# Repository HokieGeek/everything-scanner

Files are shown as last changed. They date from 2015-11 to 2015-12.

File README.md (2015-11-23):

# Olive's Scanner 

Toy I am making my toddler so that when she touches an object the "scanner" vibrates and lights up. Should second as a flashlight, of sorts.

### Prototype

Current
[Album](http://imgur.com/a/BFDh3)

## Design

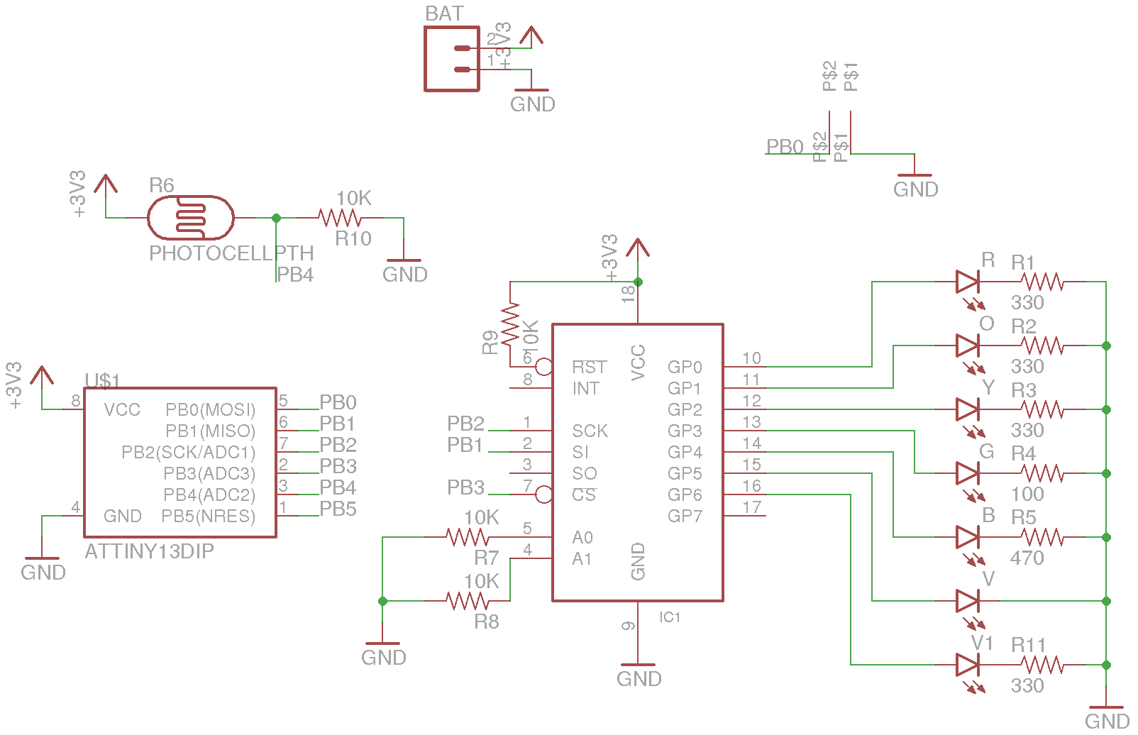
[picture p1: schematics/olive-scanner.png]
Schematics

Board

## Parts list

* [ATtiny13A](http://www.atmel.com/images/doc8126.pdf) - The driver of the whole thing
* [MCP23S08](http://www.mouser.com/ds/2/268/21919b-65915.pdf) - SPI 8-bit I/O expander used to drive just the LEDs
* [SparkFun's LED Rainbow Pack](https://www.sparkfun.com/products/13767) - Got it in a recent order for free as a christmas giveaway
* [Vibrator motor from an old phone]() - Took it out of my waterlogged MotoX :-D
* [CdS Photocell](http://cdn.sparkfun.com/datasheets/Sensors/LightImaging/SEN-09088.pdf) - When she touches this sensor to an object, the LEDs and motor activate

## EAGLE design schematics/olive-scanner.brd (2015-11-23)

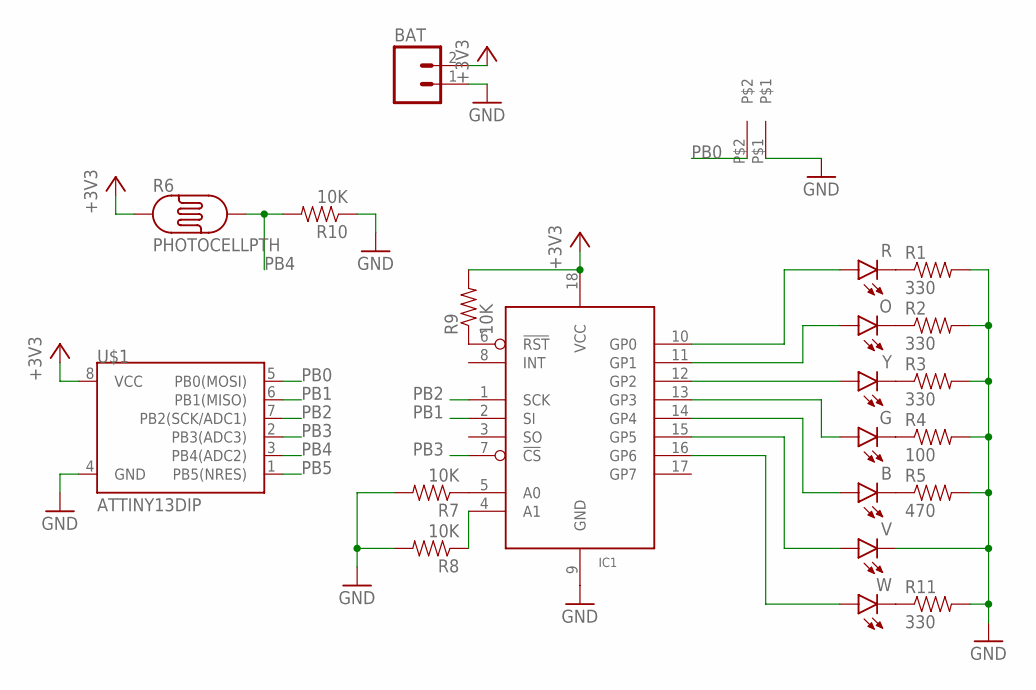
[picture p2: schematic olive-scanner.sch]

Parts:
B: LED5MM
BAT: M02LOCK; 1X02_LOCK
G: LED5MM
IC1: MCP23S08/P; DIL18
O: LED5MM
R: LED5MM
R1, R2, R3, R11: 330; AXIAL-0.3
R4: 100; AXIAL-0.3
R5: 470; AXIAL-0.3
R6: PHOTOCELLPTH; PHOTOCELL
R7, R8, R9, R10: 10K; AXIAL-0.3
U$1: ATTINY13DIP; DIP08
U$2: PHONE_VIBRATOR
V: LED5MM
W: LED5MM
Y: LED5MM

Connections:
+3V3: BAT.2, IC1.18 (VCC), R6.1, R9.P$2 (2), U$1.8 (VCC)
GND: BAT.1, IC1.9 (GND), R1.P$2 (2), R2.P$2 (2), R3.P$2 (2), R4.P$2 (2), R5.P$2 (2), R7.P$2 (2), R8.P$2 (2), R10.P$1 (1), R11.P$2 (2), U$1.4 (GND), U$2.P$1, V.K (C)
unnamed: IC1.4 (A1), R8.P$1 (1)
unnamed: IC1.6 (!RST), R9.P$1 (1)
unnamed: IC1.5 (A0), R7.P$1 (1)
unnamed: R.K (C), R1.P$1 (1)
unnamed: O.K (C), R2.P$1 (1)
unnamed: R3.P$1 (1), Y.K (C)
unnamed: G.K (C), R4.P$1 (1)
unnamed: B.K (C), R5.P$1 (1)
unnamed: R11.P$1 (1), W.K (C)
unnamed: IC1.16 (GP6), W.A
unnamed: IC1.10 (GP0), R.A
unnamed: IC1.11 (GP1), O.A
unnamed: IC1.12 (GP2), Y.A
unnamed: G.A, IC1.13 (GP3)
unnamed: B.A, IC1.14 (GP4)
unnamed: IC1.15 (GP5), V.A
PB0: U$1.5 (PB0(MOSI)), U$2.P$2
PB1: IC1.2 (SI), U$1.6 (PB1(MISO))
PB2: IC1.1 (SCK), U$1.7 (PB2(SCK/ADC1))
PB3: IC1.7 (!CS), U$1.2 (PB3(ADC3))
PB4: R6.2, R10.P$2 (2), U$1.3 (PB4(ADC2))
PB5: U$1.1 (PB5(NRES))

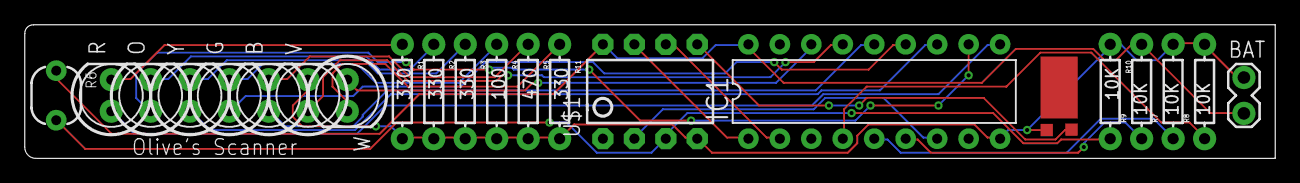
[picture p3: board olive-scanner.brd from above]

Board: 2 copper layers, 101.0 x 10.8 mm, 22 parts (0 on the bottom side), 23 nets.

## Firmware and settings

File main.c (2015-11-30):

// #define F_CPU 9600000UL

#include <avr/interrupt.h>
#include <avr/sleep.h>
#include <util/delay.h>

#include "mcp23x08.h"

#define FALSE 0
#define TRUE !(FALSE)

#define VIBRATOR_PIN PB0
#define VIBRATE_PULSE 255

#define LEDS_PIN_DATA PB1
#define LEDS_PIN_SERIALCLOCK PB2
#define LEDS_PIN_CHIPSELECT PB3
#define MCP23X08_SLAVE_ADDRESS_A0 0
#define MCP23X08_SLAVE_ADDRESS_A1 0
#define NUM_LEDS 6
#define NUM_LED_PATTERNS 4
#define ANIMATION_REPETITION 5

#define PHOTOCELL_PIN PB4
#define PHOTOCELL_ACTIVATE_THRESHOLD 330 // TODO: make this a diff from ambient?

uint8_t isAnimating = FALSE;
uint16_t currentAmbient = 800;
mcp23s08Device mcp23s08;

inline void ledsWrite(uint8_t leds) {
    MCP23S08_GpioWrite(&mcp23s08, leds);
}

void ledPattern_Alternating(void) {
    ledsWrite(0b01101010);
    _delay_ms(500);
    ledsWrite(0b01010101);
    _delay_ms(500);
}

void ledPattern_KITT(void) {
    int i = 0;
    for (; i < NUM_LEDS; i++) {
        ledsWrite(((1 << i)|(1 << NUM_LEDS)));
        _delay_ms(100);
    }
    i -= 2;
    for (; i >= 0; i--) {
        ledsWrite(((1 << i)|(1 << NUM_LEDS)));
        _delay_ms(100);
    }
}

void ledPattern_LandingStrip(void) {
    uint8_t pattern = 0;
    for (uint8_t i = 0; i < NUM_LEDS; i++) {
        pattern |= (1 << i);
        ledsWrite((pattern|(1 << NUM_LEDS)));
        _delay_ms(150);
    }
    ledsWrite(0b01000000);
    _delay_ms(150);
}

void ledPattern_Blinky(void) {
    ledsWrite(0b01111111);
    _delay_ms(500);
    ledsWrite(0b01000000);
    _delay_ms(500);
}

uint16_t readPhotocell(void) {
    uint16_t photocellVal = 0;
    for (uint8_t i = 0; i < 8; i++) {
        ADCSRA |= (1 << ADSC); // Start the conversion

        while (ADCSRA & (1 << ADSC)); // Wait for conversion

        photocellVal += ADC;
    }

    return (uint16_t)(photocellVal / 8);
}

void animateLeds(void) {
    uint16_t rand = readPhotocell() % (NUM_LED_PATTERNS-1);
    isAnimating = TRUE;
    for (uint8_t i = 0; i < ANIMATION_REPETITION && isAnimating; i++) {
        switch (rand) {
        case 0: ledPattern_Alternating(); break;
        case 1: ledPattern_KITT(); break;
        case 2: ledPattern_LandingStrip(); break;
        case 3: ledPattern_Blinky(); break;
        default: break;
        }
    }
}

inline void vibrate(uint16_t pulse) {
    OCR0A = pulse;
    _delay_ms(500);
    OCR0A = 0x00;
}

inline int isTouching(void) {
    // TODO: better way to determine this?
    if (readPhotocell() < PHOTOCELL_ACTIVATE_THRESHOLD) {
        return TRUE;
    } else {
        return FALSE;
    }
}

void analyze_and_activate(void) {
    if (isTouching()) {
        // if (isAnimating) {
        //     isAnimating = FALSE;
        // }
        vibrate(VIBRATE_PULSE);
        animateLeds();
    } else { // Turn off all LEDs
        // isAnimating = FALSE;
        ledsWrite(0x00);
    }
}

ISR(WDT_vect) {
    ADCSRA |= (1 << ADEN);  // Enable ADC
    analyze_and_activate();
    ADCSRA &= ~(1 << ADEN);  // Disable ADC
}

inline void init_pins(void) {
    // Vibrator
    TCCR0B |= (1 << CS01); // clock/8 (See 11-9)
    TCCR0A |= (1 << WGM01) | (1 << WGM00); // Set for fast PWM with 0xFF Max (See 11-8)
    TCCR0A |= (1 << COM0A1); // Clear on compare match (See 11-5)

    DDRB |= (1 << VIBRATOR_PIN);

    // LEDS
    mcp23s08.spi.chipSelect = LEDS_PIN_CHIPSELECT;
    mcp23s08.spi.serialClock = LEDS_PIN_SERIALCLOCK;
    mcp23s08.spi.serialDataInput = LEDS_PIN_DATA;

    MCP23S08_Init(MCP23X08_SLAVE_ADDRESS_A0, MCP23X08_SLAVE_ADDRESS_A1, &mcp23s08);
    MCP23S08_IodirWrite(&mcp23s08, 0x00); // Set all pins as output pins
    ledsWrite(0x00); // Start them off

    // The photocell ADC. Enable ADC2 / PB4 as an ADC pin
    ADMUX |= (0 << REFS0) | (1 << MUX1) | (0 << MUX0);
    ADCSRA |= (1 << ADPS1) | (1 << ADPS0) | (1 << ADEN); // Enable ADC and set prescaler to clock/128
}

inline void init_interrupts(void) {
    // See table 8-2 on datasheet
    WDTCR |= (1 << WDP2) | (1 << WDP0); // Sleep for ~30s
    // WDTCR |= (1 << WDP2); // Sleep for ~15s
    WDTCR |= (1 << WDTIE); // Enable watchdog timer

    sei();

    set_sleep_mode(SLEEP_MODE_PWR_DOWN);
}

int __attribute__((OS_main)) main(void) {
    init_pins();
    init_interrupts();

    ADCSRA &= ~(1 << ADEN);  // Disable ADC (to save power)

    currentAmbient = readPhotocell();

    for (;;) {
        sleep_mode();
    }

    return 0;
}

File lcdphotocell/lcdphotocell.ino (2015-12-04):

#include <SPI.h>
#include <Adafruit_GFX.h>
#include <Adafruit_PCD8544.h>
#include <avr/interrupt.h>

// Software SPI (slower updates, more flexible pin options):
// pin 7 - Serial clock out (SCLK)
// pin 6 - Serial data out (DIN)
// pin 5 - Data/Command select (D/C)
// pin 4 - LCD chip select (CS)
// pin 3 - LCD reset (RST)
Adafruit_PCD8544 display = Adafruit_PCD8544(7, 6, 5, 4, 3);

int last = 0;

void setup() {
  Serial.begin(9600);

  display.begin();

  display.setContrast(38);
  display.setTextSize(2);
  display.setTextColor(BLACK);
  
  // See table 8-2 on datasheet
  WDTCR |= (1 << WDP2) | (1 << WDP0); // Sleep for ~30s
  // WDTCR |= (1 << WDP2); // Sleep for ~15s
  WDTCR |= (1 << WDTIE); // Enable watchdog timer

  sei();

  set_sleep_mode(SLEEP_MODE_PWR_DOWN);
}

int val() {
  int v = 0;
  for (int i = 0; i < 8; i++) {
    v += analogRead(A0);
  }

  return (int)(v / 8);
}

void displayVal(int v, int d) {
  display.clearDisplay();
  display.setCursor(25,0);
  display.println(v, DEC);
  display.setCursor(35, 15);
  display.println(d, DEC);
  // display.setCursor(32, 30);
  // display.println(p, DEC);
  display.display();
  if (d < -20) {
    delay(2000);
  }
}

void doit() {
  int v = val();
  int d = v - last; // abs(last - v);
  last = v;
  Serial.print(v);
  Serial.print(", ");
  Serial.println(d); 
  displayVal(v, d);
}

ISR(WDT_vect) {
    ADCSRA |= (1 << ADEN);  // Enable ADC
    doit();
    ADCSRA &= ~(1 << ADEN);  // Disable ADC
}

// the loop routine runs over and over again forever:
void loop() {
  ADCSRA &= ~(1 << ADEN); // Disable ADC (to save power)
  sleep_mode();
  // doit();
}

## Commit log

2015-11-18 Added targets for the fuses
2015-11-18 Schematics placeholder
    [olive-scanner.sch]
2015-11-20 Fixing typo. Thanks, TravisCI!
    [main.c]
2015-11-21 Adding schematics
    [olive-scanner.brd, olive-scanner.sch]
2015-11-23 Did the schematics and updated the docs
    [olive-scanner.brd, olive-scanner.sch]
2015-11-23 Updated the prototype pic and the design images
2015-11-23 I clearly didn't compile this before committing
    Time for a git hook
    [main.c]
2015-11-23 Fixed a couple of typoish things
2015-11-23 Refactoring to make use of the spi.h impl I have
2015-11-24 Trying to put the mcp23x08 code in its own files and leverage my spi code, but SIZE!
2015-11-25 I think I have a bug passing the spi device around...
    [main.c, mcp23x08.c, spi.c]
2015-11-25 Trying to start adding the patterns. Bet I broke some stuff!
    [main.c]
2015-11-28 Randomly selecting the animations now. Only thing left is to better calibrate the sensor
2015-11-29 Refactored SPI code to allow for more reuse later
2015-11-30 Now taking many samples for a reading
2015-11-30 Adding test sketch so that I can figure out the logic I need for the light sensor to behave as I want it to

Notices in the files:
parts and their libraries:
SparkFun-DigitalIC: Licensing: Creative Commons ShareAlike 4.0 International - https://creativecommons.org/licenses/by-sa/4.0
